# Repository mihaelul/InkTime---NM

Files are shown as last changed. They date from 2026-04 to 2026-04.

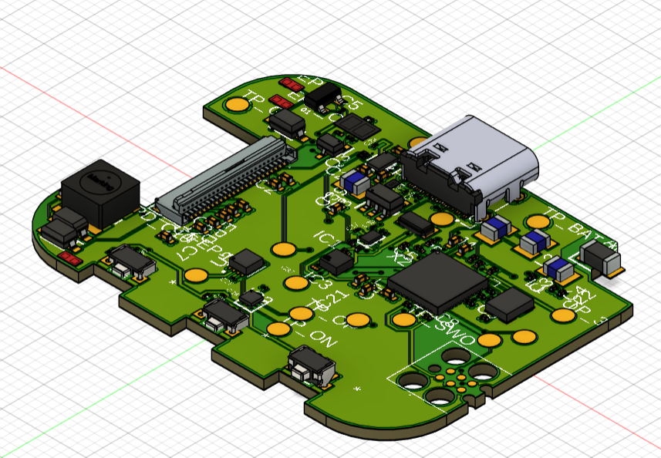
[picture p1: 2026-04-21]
Images/pcb3d-2.png

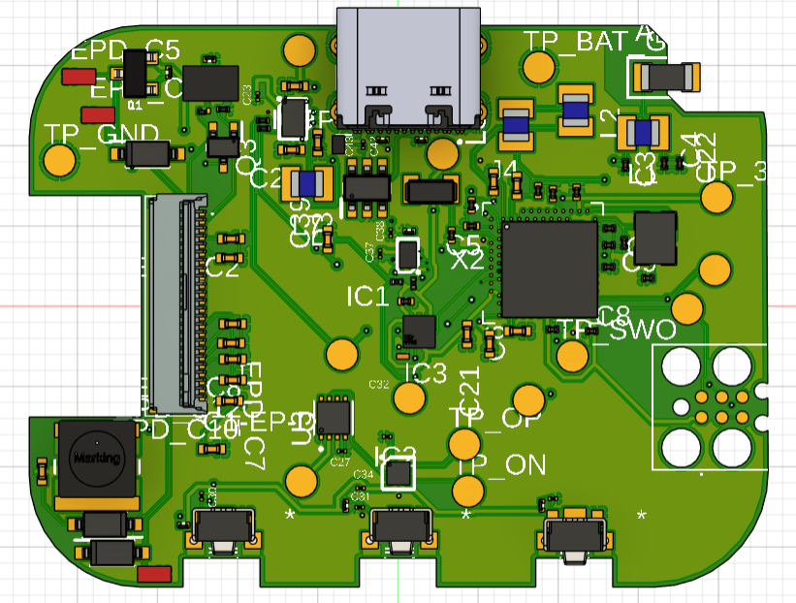
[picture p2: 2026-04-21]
Images/Front.png

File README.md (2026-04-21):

# InkTime - E-Paper Smartwatch Hardware Design

## 1. System Block Diagram
*This diagram illustrates the main hardware modules and their data/power connections to the central processing unit.*

```mermaid
graph TD

    ANTENNA[ANTENNA] ---|RF| SOC[nRF52840 <br> SoC]
    
    %% Peripherals and Interfaces
    SOC ---|I2C| IMU[IMU <br> SENSOR]
    SOC ---|SPI| EPD[E-PAPER <br> DISPLAY]
    SOC ---|PWM| SHAKER[SHAKER]
    SOC ---|GPIO| BTN[3X <br> BUTTON]
    SOC ---|SWD| DEBUG[DEBUG <br> SWD]

    USB[USB-C <br> CONNECTOR] ---|VUSB| CHARGER[CHARGER IC]
    CHARGER --- BATTERY[LI-PO BATTERY]
    CHARGER --- VREG[RT6160 <br> VOLTAGE <br> REGULATOR]
    BATTERY ---|VBAT| VREG

    %% 3V3 Power Rails
    VREG ---|3V3| IMU
    VREG ---|3V3| EPD
    VREG ---|3V3| SHAKER
```

## 1. Bill of Materials (BOM)

| Component | JLC Part # | Package | Description | Datasheet |
| :--- | :--- | :--- | :--- | :--- |
| **J1** | C122434 | SMD,P=0.5mm,Surface Mount，Right Angle | FFC & FPC Connectors 0.5mm FPC RA SMT Dual Contact 24Ckt | [datasheet](https://octopart.com/datasheet/tag-connect/TC2030-IDC) |
| **L1, L2, L3** | C12669 | 402 | Generic chip inductor | [datasheet](https://www.lcsc.com/datasheet/C12669.pdf) |
| **L5** | C1329646 | SMD,4.8x4.8mm | 1.6A 1.6A 4.7uH 41.4mΩ AEC-Q200 ±30% SMD,4.8x4.8mm Power Inductors ROHS | [datasheet](https://wmsc.lcsc.com/wmsc/upload/file/pdf/v2/lcsc/2304140030_BOURNS-SRR4828A-4R7Y_C1329646.pdf) |
| **IC3** | C189517 | LGA-12(2x2) | Accelerometers Triaxial low-g 12bit Acceleration Sensor | [datasheet](https://files.pine64.org/doc/datasheet/pinetime/BST-BMA421-FL000.pdf) |
| **Q1** | C2564 | TO-220AB | -55℃~+175℃ 1 P-Channel 180nC@10V 200W 20mΩ@10V 3.4nF 4V 55V 640pF 74A P-Channel TO-220AB MOSFETs ROHS | [datasheet](https://files.pine64.org/doc/datasheet/pinetime/BST-BMA421-FL000.pdf) |
| **U3** | C2682616 | DFN-8-EP(2x2) | -40℃~+85℃ 1 2.5V~4.5V 3uA I2C Lithium Battery DFN-8-EP(2x2) Battery Management ROHS | [datasheet](https://www.analog.com/en/products/max17048.html?ADICID=synd_ww_portfolio_pi_octopart_na_2024) |
| **ANT1** | C2917717 | 1206 | -45℃~+125℃ 0.5dBi 1.3mm 1.6mm 100MHz 2.45GHz 2W 3.2mm 50Ω Patch Antenna 1206 Antennas ROHS | [datasheet](https://www.alldatasheet.com/datasheet-pdf/pdf/348957/JOHANSON/2450AT18B100.html) |
| **D3** | C2969755 | SOT-23-6L | Low Cap. ESD Protection Auto SOT-23-6 STMicroelectronics USBLC6-2SC6Y, Dual Uni-Directional TVS Diode Array, 6-Pin SOT-23 | [datasheet](https://octopart.com/datasheet/stmicroelectronics/USBLC6-2SC6Y) |
| **X2** | C32346 | SMD3215-2P | -40℃~+85℃ 12.5pF 32.768kHz 70kΩ Crystal Oscillator ±20ppm SMD3215-2P Crystals ROHS | [datasheet](https://www.lcsc.com/datasheet/C32346.pdf) |
| **U1** | C3606653 | QFN-48(6x6) | nRF52840 | [datasheet](https://octopart.com/datasheet/nordic-semiconductor/NRF52840-QIAA-T) |
| **IC1** | C3682423 | DSBGA-8(1.1x1.6) | Charger IC Lithium Ion/Polymer, Lithium Iron Phosphate 8-DSBGA (1.6x1.1) | [datasheet](https://www.alldatasheet.com/datasheet-pdf/pdf/1359210/TI/BQ25180YBGR.html) |
| **R17-R18, R1_EP_DR, R1_USB, R2-R5, R7-R9, R_PWR_EPD, R_TYPE_SEL** | C3920633 | 0201 | 7.68k 0201 Thin Film Surface Mount Fixed Resistor +/-0.5% 870.031W CPF0201D7K68C1 |  |
| **Q3** | C469327 | SOT-323 | MOSFET N-Ch 30V 1.5A TrenchFET SC70 Vishay Si1308EDL-T1-GE3 N-channel MOSFET Transistor, 1.5 A, 30 V, 3-Pin SC-70 | [datasheet](https://4donline.ihs.com/images/VipMasterIC/IC/VISH/VISH-S-A0000692786/VISH-S-A0000692786-1.pdf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) |
| **SW_DN, SW_ENT, SW_UP** | C569760 | SMD,3.9x2.9mm | -40℃~+85℃ 1.6N 1.6mm 15V 2.9mm 20mA 3.9mm 500,000 Cycles IP67 J-Lead Rectangular Button SPST Surface Mount White With Bracket | [datasheet](https://wmsc.lcsc.com/wmsc/upload/file/pdf/v2/lcsc/2301111010_PANASONIC-EVPAKE31A_C569760.pdf) |
| **L7** | C5832368 | 1008 | 13mΩ 470nH 6.5A 7.5A ±20% 1008 Power Inductors ROHS | [datasheet](https://www.lcsc.com/datasheet/C5832368.pdf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) |
| **IC9** | C7065276 | WLCSP-15B(2.3x1.4) | Buck-Boost Regulator Positive Output Step-Up/Step-Down I2C DC-DC Controller IC 15-WL-CSP | [datasheet](https://www.alldatasheet.com/datasheet-pdf/pdf/1709403/RICHTEK/RT6160AWSC.html) |
| **J4** | C709357 | SMD | 16P Female Surface Mount, Right Angle Type-C SMD USB Connectors ROHS | [datasheet](https://www.lcsc.com/datasheet/C709357.pdf) |
| **IC2** | C81079 | DSBGA-9 | Haptic Driver for ERM/LRA with Built-In Library and Smart Loop Architecture | [datasheet](https://www.alldatasheet.com/datasheet-pdf/pdf/489356/TI/DRV2605.html) |
| **D2, D4, D5** | C82046 | SOD-123 | ON SEMICONDUCTOR - MBR0530 - DIODE, SCHOTTKY, 0.5A, 30V, SOD-123 | [datasheet](https://www.lcsc.com/datasheet/C82046.pdf) |
| **X1** | C9009 | SMD3225-4P | 32MHz Crystal Oscillator ±10ppm ±20ppm SMD3225-4P Crystals ROHS | [datasheet](https://www.lcsc.com/datasheet/C9009.pdf) |
| **J2** | C90533 | P=1mm | CABLE ADAPTER 6 POS | https://octopart.com/datasheet/tag-connect/TC2030-IDC |
| **C6, C14, C15, C20, C21, C24, C25, C33, C39** | C9900179830 | 0402 | Generic chip capacitor |  [datasheet](https://octopart.com/datasheet/kyocera-avx/0402YC104KAT2A) |
| **EPD_C1 - EPD_C12** | C9900179830 | 0402 | Generic chip capacitor | [datasheet](https://octopart.com/datasheet/kyocera-avx/0402YC104KAT2A) |
| **C1, C2, C3, C4, C5, C7, C8, C9, C10, C11, C12, C13, C16, C17, C18, C19** | C9900156064 | 0201 | Generic chip capacitor | [datasheet](https://www.we-online.com/components/products/datasheet/885012104003.pdf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) |

## 3. Hardware Functionality & Specifications

The InkTime hardware architecture is centered around a **30-day battery life** target, utilizing an ultra-low-power interrupt-driven design.

### 1. Core Processing & Connectivity
* **SoC:** **nRF52840** (ARM Cortex-M4F) handles BLE 5.0 connectivity and main system logic.
* **Clocking:** 32MHz crystal for high-speed operations and a 32.768kHz crystal for accurate RTC timekeeping during sleep.
* **Programming:** Integrated **SWD** interface accessible via a Tag-Connect TC2030 footprint.

### 2. Power Management System
* **Battery:** **250mAh LiPo** (AKYGA LP502030) providing the primary power source.
* **Charging:** **BQ25180** charger IC manages USB charging via I2C and signals MCU on power events.
* **Regulation:** **RT6160** Buck-Boost converter stabilizes the 3.3V system rail across the full battery voltage range.
* **Monitoring:** **MAX17048** Fuel Gauge tracks battery State of Charge (SoC) via I2C with precision.

### 3. Display & User Interface
* **Display:** **1.54" E-Paper** (200x200) connected via **SPI**.
* **Power Gating:** An **SI2301 P-FET** switch is used to completely cut power to the display circuit between refreshes to eliminate leakage.
* **Refresh Policy:** Partial refresh is triggered once per minute to minimize energy consumption.
* **Input:** Three side-mounted tactile buttons (Up, Down, Enter/Esc) configured with internal pull-ups and wake-on-low interrupts.

### 4. Sensors & Haptics (I2C Bus)
* **Motion Sensing:** **BMA421** Accelerometer provides step counting and gesture wake-up functionality.
* **Haptic Feedback:** **DRV2605L** driver controls an **ERM vibration motor** to provide tactile notifications.
* **Efficiency:** Both modules are strictly managed; the haptic driver is disabled via an Enable pin when not in use.

### 5. Energy Profile
* **Sleep Current:** System spends >95% of time in deep sleep with peripherals powered down.
* **Active Peaks:** Energy is primarily consumed during BLE transfers and 1-minute display updates (~8mAs per update).

## 4. Detailed Pinout & Design Justification (nRF52840)

The pin mapping for the nRF52840 was optimized for **Power Efficiency**, **Signal Integrity (RF)**, and **PCB Routing** (minimizing via count and crossing traces).

### Communication & Power Control
| Pin | Net Name | Component | Justification |
| :--- | :--- | :--- | :--- |
| **ANT** | RF_OUT | Ceramic Antenna | Dedicated RF output requiring a 50Ω matched trace to the antenna network. |
| **P0.06 / P0.07** | I2C_SDA / SCL | Shared I2C Bus | Shared bus for BMA421, MAX17048, DRV2605L, and BQ25180 to conserve pins and simplify routing. |
| **P0.02 / P0.03** | EPD_SCK / MOSI | E-Paper (SPI) | High-speed SPI clock and data for the display. |
| **P0.05** | EPD_CS | E-Paper (SPI) | Chip Select to keep the EPD controller inactive when the bus is shared. |
| **P0.15 / P0.16** | EPD_DC / RST | E-Paper Control | Dedicated pins for Data/Command toggling and hardware reset. |
| **P0.17** | EPD_BUSY | E-Paper Status | Monitors internal state, allowing the MCU to sleep during EPD refresh cycles. |
| **P1.01** | PWR_EPD | P-FET Gate (Q4) | **Critical:** High-side power gating to physically cut power to the EPD, eliminating standby leakage. |

### User Input & Interrupts
| Pin | Net Name | Component | Justification |
| :--- | :--- | :--- | :--- |
| **P0.13 / P0.14** | SW_UP / SW_DN | Nav Buttons | Configured with internal pull-ups. Supports "Wake-on-Low" to wake the SoC from deep sleep. |
| **P1.00** | SW_ENT | Enter Button | Placed on Port 1 to simplify physical trace routing to the right edge of the PCB. |
| **P0.08** | IMU_INT1 | BMA421 (INT) | Primary interrupt for step detection, waking the MCU only when necessary. |
| **P0.12** | HAPTIC_EN | DRV2605L | Completely disables the haptic driver IC when inactive to save microamps of quiescent current. |

### System Timing & Debug
| Pin | Net Name | Component | Justification |
| :--- | :--- | :--- | :--- |
| **XC1 / XC2** | 32M_XTAL | 32MHz Crystal | Essential for BLE radio operation and high-accuracy internal timing. |
| **XL1 / XL2** | 32K_XTAL | 32.768kHz Crystal | Low-power clock for the RTC, keeping time while the system is in deep sleep. |
| **SWDIO / CLK**| SWD_DATA / CLK | Tag-Connect J2 | Standard ARM programming interface, placed near the edge for easy access. |

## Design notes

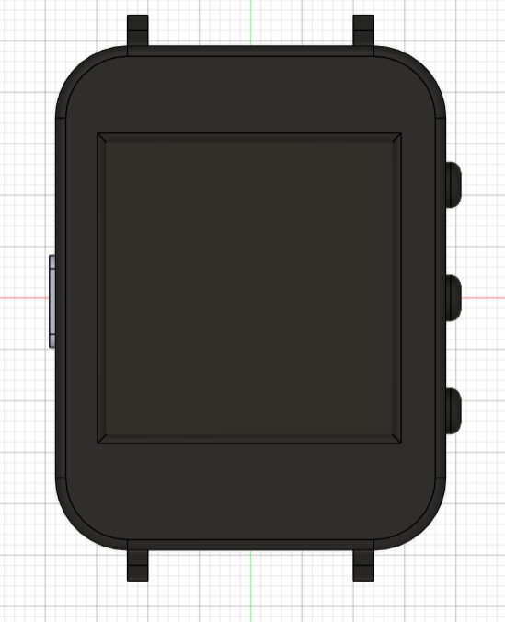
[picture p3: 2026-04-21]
Images/watch1.png

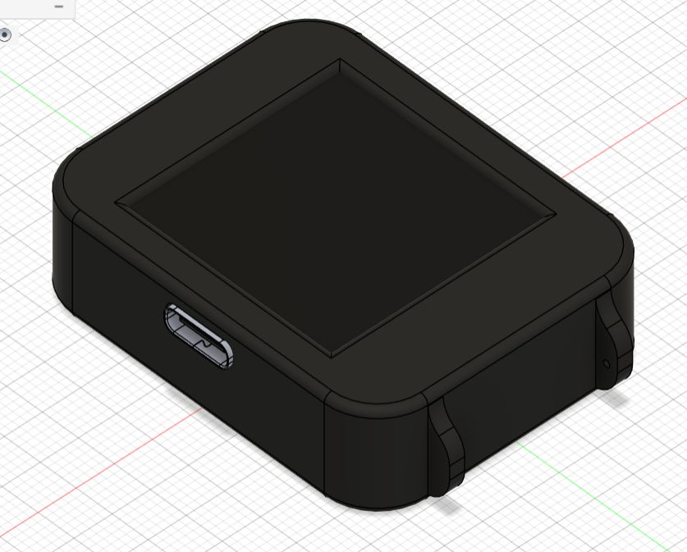
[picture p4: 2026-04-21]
Images/watch2.png

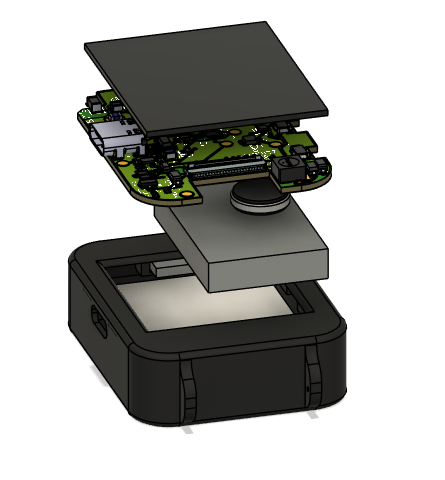
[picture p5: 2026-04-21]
Images/exploded.png

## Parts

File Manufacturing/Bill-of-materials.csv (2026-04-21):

Qty | Value | Device | Package | Parts | Description | ARROW_PART_NUMBER | ARROW_PRICE-STOCK | AVAILABILITY | CHECK_PRICES | COPYRIGHT | DESCRIPTION | DIGI-KEY_PART_NUMBER_1 | DIGI-KEY_PART_NUMBER_2 | DIGI-KEY_PART_NUMBER_3 | HEIGHT | JLCPCB | MANUFACTURER_NAME | MANUFACTURER_PART_NUMBER | MF | MFR_NAME | MOUSER_PART_NUMBER | MOUSER_PRICE-STOCK | MP | PACKAGE | POPULARITY | PRICE | PROD_ID | PURCHASE-URL | SNAPEDA_LINK | TP_SIGNAL_NAME | VALUE
1 |  | ESP32_C6_LIBRARY_7_JUMPER_SJ | ESP32_C6_LIBRARY_7_JUMPER_SJ | SJ1 | SMD solder JUMPER |  |  |  |  |  |  |  |  |  |  |  |  |  |  |  |  |  |  |  | 3
3 | 0 | CPF0201D7K68C1_CPF0201D7K68C1 | CPF0201D7K68C1_0201 | R2, R3, R4 | 7.68k 0201 Thin Film Surface Mount Fixed Resistor +/-0.5% 0.031W CPF0201D7K68C1
4 | 0.1uF | GRM011R60J152KE01L_2_GRM011R60J152KE01L | GRM011R60J152KE01L_2_CAPC0201X13N | C23, C27, C34, C42 | Check availability |  |  | In Stock | https://www.snapeda.com/parts/GRM011R60J152KE01L/Murata/view-part/?ref=eda |  | SMD Capacitor X5R(EIA) with Capacitance: 1500pF Tol. 10%. Rated Voltage: 6.3Vdc |  |  |  |  |  |  |  | Murata |  |  |  | GRM011R60J152KE01L | 0201 Murata |  | None |  |  | https://www.snapeda.com/parts/GRM011R60J152KE01L/Murata/view-part/?ref=snap
8 | 0.1uF/50V | NORDIC_NRF_3_CAPACITOR_0402_N | NORDIC_NRF_3_RESC0402_N | EPD_C5, EPD_C6, EPD_C7, EPD_C8, EPD_C9, EPD_C10, EPD_C11, EPD_C12 | Generic chip capacitor
1 | 0.47 | CPF0201D7K68C1_CPF0201D7K68C1 | CPF0201D7K68C1_0201 | R1_EP_DR | 7.68k 0201 Thin Film Surface Mount Fixed Resistor +/-0.5% 0.031W CPF0201D7K68C1
1 | 1.0µF | NORDIC_NRF_3_CAPACITOR_0402_N | NORDIC_NRF_3_RESC0402_N | C15 | Generic chip capacitor
2 | 100nF | NORDIC_NRF_3_CAPACITOR_0201_L | NORDIC_NRF_3_RESC0201_L | C7, C8 | Generic chip capacitor
3 | 100nF | NORDIC_NRF_3_CAPACITOR_0201_N | NORDIC_NRF_3_RESC0201_N | C5, C12, C19 | Generic chip capacitor
1 | 100pF | NORDIC_NRF_3_CAPACITOR_0201_L | NORDIC_NRF_3_RESC0201_L | C11 | Generic chip capacitor
2 | 10K | CPF0201D7K68C1_CPF0201D7K68C1 | CPF0201D7K68C1_0201 | R9, R_PWR_EPD | 7.68k 0201 Thin Film Surface Mount Fixed Resistor +/-0.5% 0.031W CPF0201D7K68C1
4 | 10k | CPF0201D7K68C1_CPF0201D7K68C1 | CPF0201D7K68C1_0201 | R2_EP_DR, R5, R7, R8 | 7.68k 0201 Thin Film Surface Mount Fixed Resistor +/-0.5% 0.031W CPF0201D7K68C1
3 | 10uF | NORDIC_NRF_3_CAPACITOR_0402_N | NORDIC_NRF_3_RESC0402_N | C1-EP-DR, C24, C39 | Generic chip capacitor
1 | 10µH | MLP2016SR47MT0S1_FTC252012SR47MBCA | MLP2016SR47MT0S1_INDC2016X100N | L2 | SMD / SMT Inductors (Coils), L=0.47?H, L x W x T : |  |  |  |  |  | SMD / SMT Inductors (Coils) | L=0.47?H | L x W x T : |  |  |  | 1mm | https://jlcpcb.com/partdetail/6763488-FTC252012SR47MBCA/C5832368 | TDK | FTC252012SR47MBCA
2 | 12pF | NORDIC_NRF_3_CAPACITOR_0201_L | NORDIC_NRF_3_RESC0201_L | C1, C2 | Generic chip capacitor
2 | 12pF | NORDIC_NRF_3_CAPACITOR_0201_N | NORDIC_NRF_3_RESC0201_N | C17, C18 | Generic chip capacitor
1 | 15nH | MLP2016SR47MT0S1_FTC252012SR47MBCA | MLP2016SR47MT0S1_INDC2016X100N | L3 | SMD / SMT Inductors (Coils), L=0.47?H, L x W x T : |  |  |  |  |  | SMD / SMT Inductors (Coils) | L=0.47?H | L x W x T : |  |  |  | 1mm | https://jlcpcb.com/partdetail/6763488-FTC252012SR47MBCA/C5832368 | TDK | FTC252012SR47MBCA
2 | 1pF | NORDIC_NRF_3_CAPACITOR_0201_L | NORDIC_NRF_3_RESC0201_L | C3, C4 | Generic chip capacitor
6 | 1uF | GRM011R60J152KE01L_2_GRM011R60J152KE01L | GRM011R60J152KE01L_2_CAPC0201X13N | C29, C30, C31, C32, C37, C38 | Check availability |  |  | In Stock | https://www.snapeda.com/parts/GRM011R60J152KE01L/Murata/view-part/?ref=eda |  | SMD Capacitor X5R(EIA) with Capacitance: 1500pF Tol. 10%. Rated Voltage: 6.3Vdc |  |  |  |  |  |  |  | Murata |  |  |  | GRM011R60J152KE01L | 0201 Murata |  | None |  |  | https://www.snapeda.com/parts/GRM011R60J152KE01L/Murata/view-part/?ref=snap
2 | 1uF/50V | NORDIC_NRF_3_CAPACITOR_0402_N | NORDIC_NRF_3_RESC0402_N | EPD_C1, EPD_C2 | Generic chip capacitor
1 | 2.2 | CPF0201D7K68C1_CPF0201D7K68C1 | CPF0201D7K68C1_0201 | R_TYPE_SEL | 7.68k 0201 Thin Film Surface Mount Fixed Resistor +/-0.5% 0.031W CPF0201D7K68C1
3 | 2025-10-22_07-23-44_LIBRARY_EVP-AKE31ASW_EVP-AKE31A_PAN | 2025-10-22_07-23-44_LIBRARY_EVP-AKE31ASW_EVP-AKE31A_PAN | 2025-10-22_07-23-44_LIBRARY_SW_EVP-AKE31A_PAN | SW_DN, SW_ENT, SW_UP |  |  |  |  |  | Copyright (C) 2025 Ultra Librarian. All rights reserved. |  | P123437TR-ND | P123437CT-ND | P123437DKR-ND |  |  | Panasonic | EVP-AKE31A
1 | 20V/4.2A/52mO/1.4W | ESP32_C6_LIBRARY_4_ESP32_WROVER_SPARKFUN-DISCRETESEMI_MOSFET_PCH-DMG2305UX-7 | ESP32_C6_LIBRARY_4_ESP32_C6_LIBRARY_4_ESP32_C6_LIBRARY_4_ESP32_C6_LIBRARY_4_ESP32_WROVER_SPARKFUN-DISCRETESEMI_SOT23-3 | Q1 | P-channel MOSFETs |  |  |  |  |  |  |  |  |  |  |  |  |  |  |  |  |  |  |  |  |  | TRAN-14388 |  |  |  | 20V/4.2A/52mO/1.4W
2 | 22uF | NORDIC_NRF_3_CAPACITOR_0402_N | NORDIC_NRF_3_RESC0402_N | C25, C33 | Generic chip capacitor
1 | 2450AT18B100E_2450AT18B100E | 2450AT18B100E_2450AT18B100E | 2450AT18B100E_ANTC3216X140N | ANT1 | Antennas 2.45GHz ANTENNA | 2450AT18B100E | https://www.arrow.com/en/products/2450at18b100e/johanson-dielectrics?utm_currency=USD&region=nac |  |  |  | Antennas 2.45GHz ANTENNA |  |  |  | 1.4mm |  | JOHANSON TECHNOLOGY | 2450AT18B100E |  |  | 609-2450AT18B100E | https://www.mouser.co.uk/ProductDetail/Johanson-Technology/2450AT18B100E?qs=yCnrNFeXz%252Bh5MFsFIXGZGA%3D%3D
1 | 3.9nH | MLP2016SR47MT0S1_FTC252012SR47MBCA | MLP2016SR47MT0S1_INDC2016X100N | L1 | SMD / SMT Inductors (Coils), L=0.47?H, L x W x T : |  |  |  |  |  | SMD / SMT Inductors (Coils) | L=0.47?H | L x W x T : |  |  |  | 1mm | https://jlcpcb.com/partdetail/6763488-FTC252012SR47MBCA/C5832368 | TDK | FTC252012SR47MBCA
1 | 32.768kHz | NORDIC_NRF_1_XTAL_32KHZ | NORDIC_NRF_1_XTAL_3215_N | X2
1 | 32MHz | NORDIC_NRF_XTAL_32MHZ | NORDIC_NRF_BT-XTAL_2016_N | X1
2 | 3K3 | CPF0201D7K68C1_CPF0201D7K68C1 | CPF0201D7K68C1_0201 | R17, R18 | 7.68k 0201 Thin Film Surface Mount Fixed Resistor +/-0.5% 0.031W CPF0201D7K68C1
1 | 4.7uF | GRM011R60J152KE01L_2_GRM011R60J152KE01L | GRM011R60J152KE01L_2_CAPC0201X13N | C43 | Check availability |  |  | In Stock | https://www.snapeda.com/parts/GRM011R60J152KE01L/Murata/view-part/?ref=eda |  | SMD Capacitor X5R(EIA) with Capacitance: 1500pF Tol. 10%. Rated Voltage: 6.3Vdc |  |  |  |  |  |  |  | Murata |  |  |  | GRM011R60J152KE01L | 0201 Murata |  | None |  |  | https://www.snapeda.com/parts/GRM011R60J152KE01L/Murata/view-part/?ref=snap
1 | 4.7uF/25V | NORDIC_NRF_3_CAPACITOR_0402_N | NORDIC_NRF_3_RESC0402_N | C2-EP-DR | Generic chip capacitor
4 | 4.7µF | NORDIC_NRF_3_CAPACITOR_0402_N | NORDIC_NRF_3_RESC0402_N | C6, C14, C20, C21 | Generic chip capacitor
1 | 47nF | NORDIC_NRF_3_CAPACITOR_0201_N | NORDIC_NRF_3_RESC0201_N | C16 | Generic chip capacitor
1 | 503480-2400_503480-2400 | 503480-2400_503480-2400 | 503480-2400_5034802400 | J3 | FFC & FPC Connectors 0.5mm FPC RA SMT Dual Contact 24Ckt |  |  |  |  |  | FFC & FPC Connectors 0.5mm FPC RA SMT Dual Contact 24Ckt |  |  |  | 1.87mm |  | Molex | 503480-2400 |  |  | 538-503480-2400 | https://www.mouser.co.uk/ProductDetail/Molex/503480-2400?qs=OAhjpuo3Vu7efIoxFh9AOw%3D%3D
2 | 5k1 | ERA-1AEB3401C_CPF0201D7K68C1 | ERA-1AEB3401C_0201 | R1_USB, R2_USB | 7.68k 0201 Thin Film Surface Mount Fixed Resistor +/-0.5% 0.031W CPF0201D7K68C1
1 | 68uH | ESP32_C6_LIBRARY_2_744043680IND_4828-WE-TPC_WRE | ESP32_C6_LIBRARY_2_IND_4828-WE-TPC_WRE | L5 |  |  |  |  |  | Copyright (C) 2024 Ultra Librarian. All rights reserved. |  |  |  |  |  |  |  | 744043680 |  | Wurth Electronics
1 | 820pF | NORDIC_NRF_3_CAPACITOR_0201_L | NORDIC_NRF_3_RESC0201_L | C9 | Generic chip capacitor
1 | BMA423_BMA423 | BMA423_BMA423 | BMA423_BMA423 | IC3 | Accelerometers Triaxial low-g 12bit Acceleration Sensor | BMA423 | https://www.arrow.com/en/products/bma423/bosch |  |  |  | Accelerometers Triaxial low-g 12bit Acceleration Sensor |  |  |  | 1mm |  | BOSCH | BMA423 |  |  | 262-BMA423 | https://www.mouser.co.uk/ProductDetail/Bosch-Sensortec/BMA423?qs=HXFqYaX1Q2xC%252BSgeGoX3mg%3D%3D
1 | BQ25180YBGR_BQ25180YBGR | BQ25180YBGR_BQ25180YBGR | BQ25180YBGR_BGA8C40P2X4_100X155X50 | IC1 | Charger IC Lithium Ion/Polymer, Lithium Iron Phosphate 8-DSBGA (1.6x1.1) | BQ25180YBGR | https://www.arrow.com/en/products/bq25180ybgr/texas-instruments?utm_currency=USD&region=nac |  |  |  | Charger IC Lithium Ion/Polymer | Lithium Iron Phosphate 8-DSBGA (1.6x1.1) |  |  |  | 0.5mm |  | Texas Instruments | BQ25180YBGR |  |  | 595-BQ25180YBGR | https://www.mouser.co.uk/ProductDetail/Texas-Instruments/BQ25180YBGR?qs=doiCPypUmgEWjAK%252BJAX6Tw%3D%3D
1 | DRV2605YZFR_DRV2605YZFR | DRV2605YZFR_DRV2605YZFR | DRV2605YZFR_BGA9C50P3X3_144X144X62 | IC2 | Haptic Driver for ERM/LRA with Built-In Library and Smart Loop Architecture | DRV2605YZFR | https://www.arrow.com/en/products/drv2605yzfr/texas-instruments?region=nac |  |  |  | Haptic Driver for ERM/LRA with Built-In Library and Smart Loop Architecture |  |  |  | 0.625mm |  | Texas Instruments | DRV2605YZFR
1 | ESP32_C6_LIBRARY_3_USBLC6-2SC6Y | ESP32_C6_LIBRARY_3_USBLC6-2SC6Y | ESP32_C6_LIBRARY_3_SOT95P280X145-6N | D3 | Low Cap. ESD Protection Auto SOT-23-6 STMicroelectronics USBLC6-2SC6Y, Dual Uni-Directional TVS Diode Array, 6-Pin SOT-23 |  |  | In Stock | https://www.snapeda.com/parts/USBLC6-2SC6Y/STMicroelectronics/view-part/?ref=eda |  | 17V Clamp 5A (8/20µs) Ipp Tvs Diode Surface Mount SOT-23-6 |  |  |  |  |  |  |  | STMicroelectronics |  |  |  | USBLC6-2SC6Y | SOT-23-6 STMicroelectronics |  | None |  |  | https://www.snapeda.com/parts/USBLC6-2SC6Y/STMicroelectronics/view-part/?ref=snap
1 | ESP32_C6_LIBRARY_MAX17048G+T10 | ESP32_C6_LIBRARY_MAX17048G+T10 | ESP32_C6_LIBRARY_SON50P200X200X80-9N | U3 | Check availability |  |  | In Stock | https://www.snapeda.com/parts/MAX17048G+T10/Analog+Devices/view-part/?ref=eda |  | 3µA 1-Cell/2-Cell Fuel Gauge with ModelGauge |  |  |  |  |  |  |  | Analog Devices |  |  |  | MAX17048G+T10 | TDFN-8 Maxim |  | None |  | https://www.snapeda.com/api/url_track_click_mouser/?unipart_id=329239&manufacturer=Analog Devices&part_name=MAX17048G+T10&search_term=None | https://www.snapeda.com/parts/MAX17048G+T10/Analog+Devices/view-part/?ref=snap
14 | HECTOR_WATCH_1_TPTP20R | HECTOR_WATCH_1_TPTP20R | HECTOR_WATCH_1_TP20R | TP_3.3V, TP_3V3, TP_BAT_GND, TP_GND, TP_ON, TP_OP, TP_RESET, TP_SCL, TP_SDA, TP_SWDCLK, TP_SWDIO, TP_SWO, TP_VBAT, TP_VREG | Test pad |  |  |  |  |  |  |  |  |  |  |  |  |  |  |  |  |  |  |  | 2
1 | KH-TYPE-C-16P_KH-TYPE-C-16P | KH-TYPE-C-16P_KH-TYPE-C-16P | KH-TYPE-C-16P_KINGHELM_KH-TYPE-C-16P | J4 | Check availability |  |  | Not in stock | https://www.snapeda.com/parts/KH-TYPE-C-16P/Kinghelm/view-part/?ref=eda |  |  |  |  |  |  |  |  |  | kinghelm |  |  |  | KH-TYPE-C-16P | None |  | None |  |  | https://www.snapeda.com/parts/KH-TYPE-C-16P/Kinghelm/view-part/?ref=snap
3 | MBR0530 | ESP32_C6_LIBRARY_5_MBR0530 | ESP32_C6_LIBRARY_5_SOD3716X135N | D2, D4, D5 | ON SEMICONDUCTOR - MBR0530 - DIODE, SCHOTTKY, 0.5A, 30V, SOD-123 |  |  | In Stock | https://www.snapeda.com/parts/MBR0530/Onsemi/view-part/?ref=eda |  | Diode Schottky 30 V 500mA Surface Mount SOD-123 |  |  |  |  |  |  |  | ON Semiconductor |  |  |  | MBR0530 | SOD-123-2 ON Semiconductor |  | None |  | https://www.snapeda.com/api/url_track_click_mouser/?unipart_id=179458&manufacturer=ON Semiconductor&part_name=MBR0530&search_term=None | https://www.snapeda.com/parts/MBR0530/Onsemi/view-part/?ref=snap
1 | MLP2016SR47MT0S1_FTC252012SR47MBCA | MLP2016SR47MT0S1_FTC252012SR47MBCA | MLP2016SR47MT0S1_INDC2016X100N | L7 | SMD / SMT Inductors (Coils), L=0.47?H, L x W x T : |  |  |  |  |  | SMD / SMT Inductors (Coils) | L=0.47?H | L x W x T : |  |  |  | 1mm | https://jlcpcb.com/partdetail/6763488-FTC252012SR47MBCA/C5832368 | TDK | FTC252012SR47MBCA
1 | N.C | NORDIC_NRF_3_CAPACITOR_0201_N | NORDIC_NRF_3_RESC0201_N | C13 | Generic chip capacitor
2 | N.C. | NORDIC_NRF_3_CAPACITOR_0201_L | NORDIC_NRF_3_RESC0201_L | C10, C22 | Generic chip capacitor
1 | NORDIC_NRF_4_NRF52840_QF | NORDIC_NRF_4_NRF52840_QF | NORDIC_NRF_4_AQFN50P700X700X85_HS-74N | U$1 | nRF52840
1 | RT6160AWSC_RT6160AWSC | RT6160AWSC_RT6160AWSC | RT6160AWSC_BGA15C40P3X5_140X230X60 | IC9 | Buck-Boost Regulator Positive Output Step-Up/Step-Down I2C DC-DC Controller IC 15-WL-CSP (BSC) (1.4x2.3) |  |  |  |  |  | Buck-Boost Regulator Positive Output Step-Up/Step-Down I2C DC-DC Controller IC 15-WL-CSP (BSC) (1.4x2.3) |  |  |  | 0.6mm |  | RICHTEK | RT6160AWSC |  |  | 835-RT6160AWSC | https://www.mouser.co.uk/ProductDetail/Richtek/RT6160AWSC?qs=amGC7iS6iy%2FLd9PSoixZXQ%3D%3D
1 | SI1308EDL-T1-GE3 | ESP32_C6_LIBRARY_6_SI1308EDL-T1-GE3 | ESP32_C6_LIBRARY_6_SOT65P210X110-3N | Q3 | MOSFET N-Ch 30V 1.5A TrenchFET SC70 Vishay Si1308EDL-T1-GE3 N-channel MOSFET Transistor, 1.5 A, 30 V, 3-Pin SC-70 |  |  | In Stock | https://www.snapeda.com/parts/SI1308EDL-T1-GE3/Vishay+Siliconix/view-part/?ref=eda |  | Si1308EDL-T1-GE3 N-channel MOSFET Transistor | 1.5 A | 30 V | 3-Pin SC-70 | Siliconix / Vishay SI1308EDL-T1-GE3 |  |  |  |  |  |  |  | Vishay Siliconix |  |  |  | SI1308EDL-T1-GE3 | SOT-323 Vishay Semiconductor |  | None |  | https://www.snapeda.com/api/url_track_click_mouser/?unipart_id=274603&manufacturer=Vishay Siliconix&part_name=SI1308EDL-T1-GE3&search_term=None
1 | TC2030-IDC_TC2030-IDC | TC2030-IDC_TC2030-IDC | TC2030-IDC_TC2030IDC | J2 | CABLE ADAPTER 6 POS |  |  |  |  |  | CABLE ADAPTER 6 POS |  |  |  | 19mm |  | Tag Connect | TC2030-IDC

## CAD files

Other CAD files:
Mechanical/3dpcb.f3z

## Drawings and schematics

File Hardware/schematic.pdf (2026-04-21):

# E-Paper Drive Circuit Haptic Driver

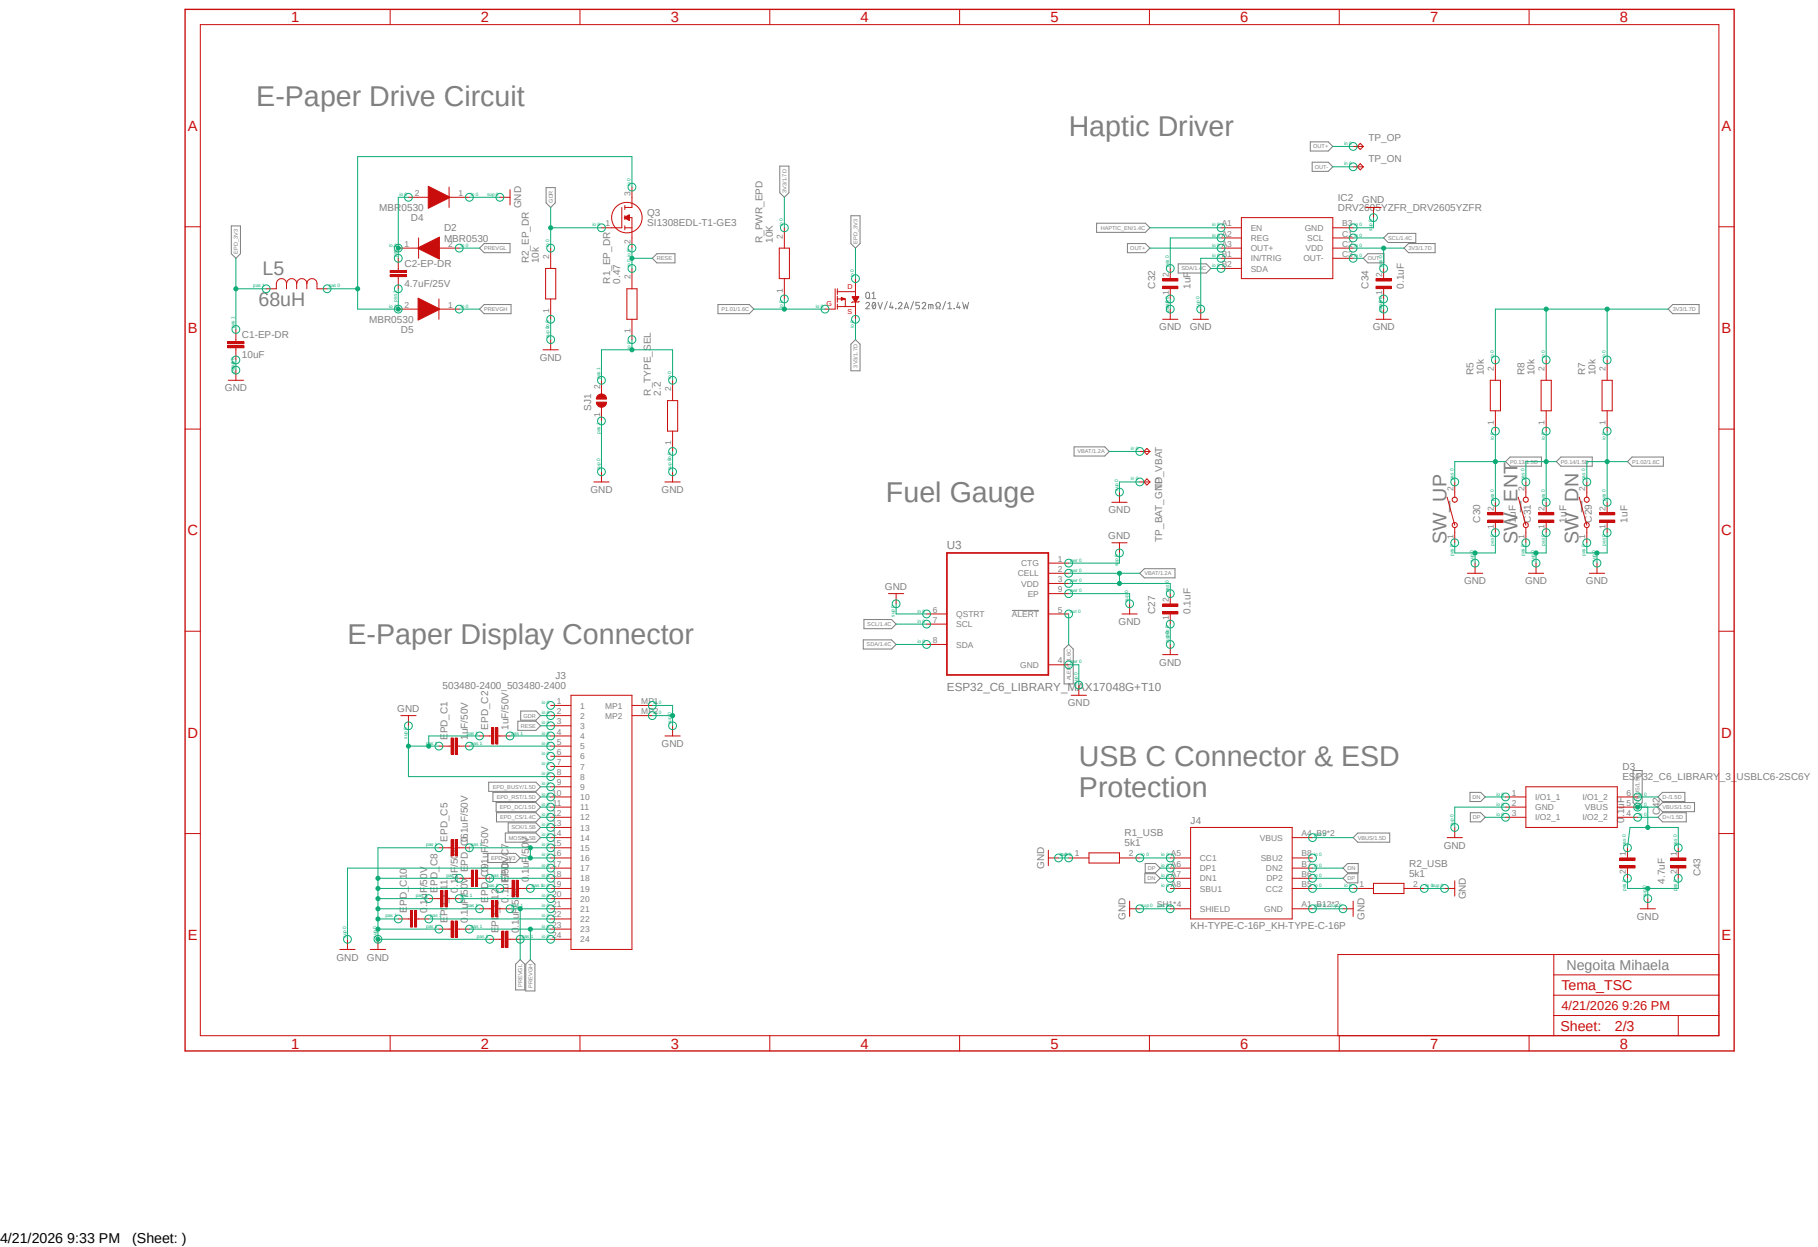
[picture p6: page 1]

pas 1 | pas 1 io 0 | 18 18

pas 1 | pas 1 | io 0 | 20 20

pas 1 | pas 1 io 0 | 19 19

pas 1 | pas 1 io 0 | 21 21

pas 1 | pas 1 | | io 0 | 22 22

pas 1 | pas 1 | io 0 | 23 23

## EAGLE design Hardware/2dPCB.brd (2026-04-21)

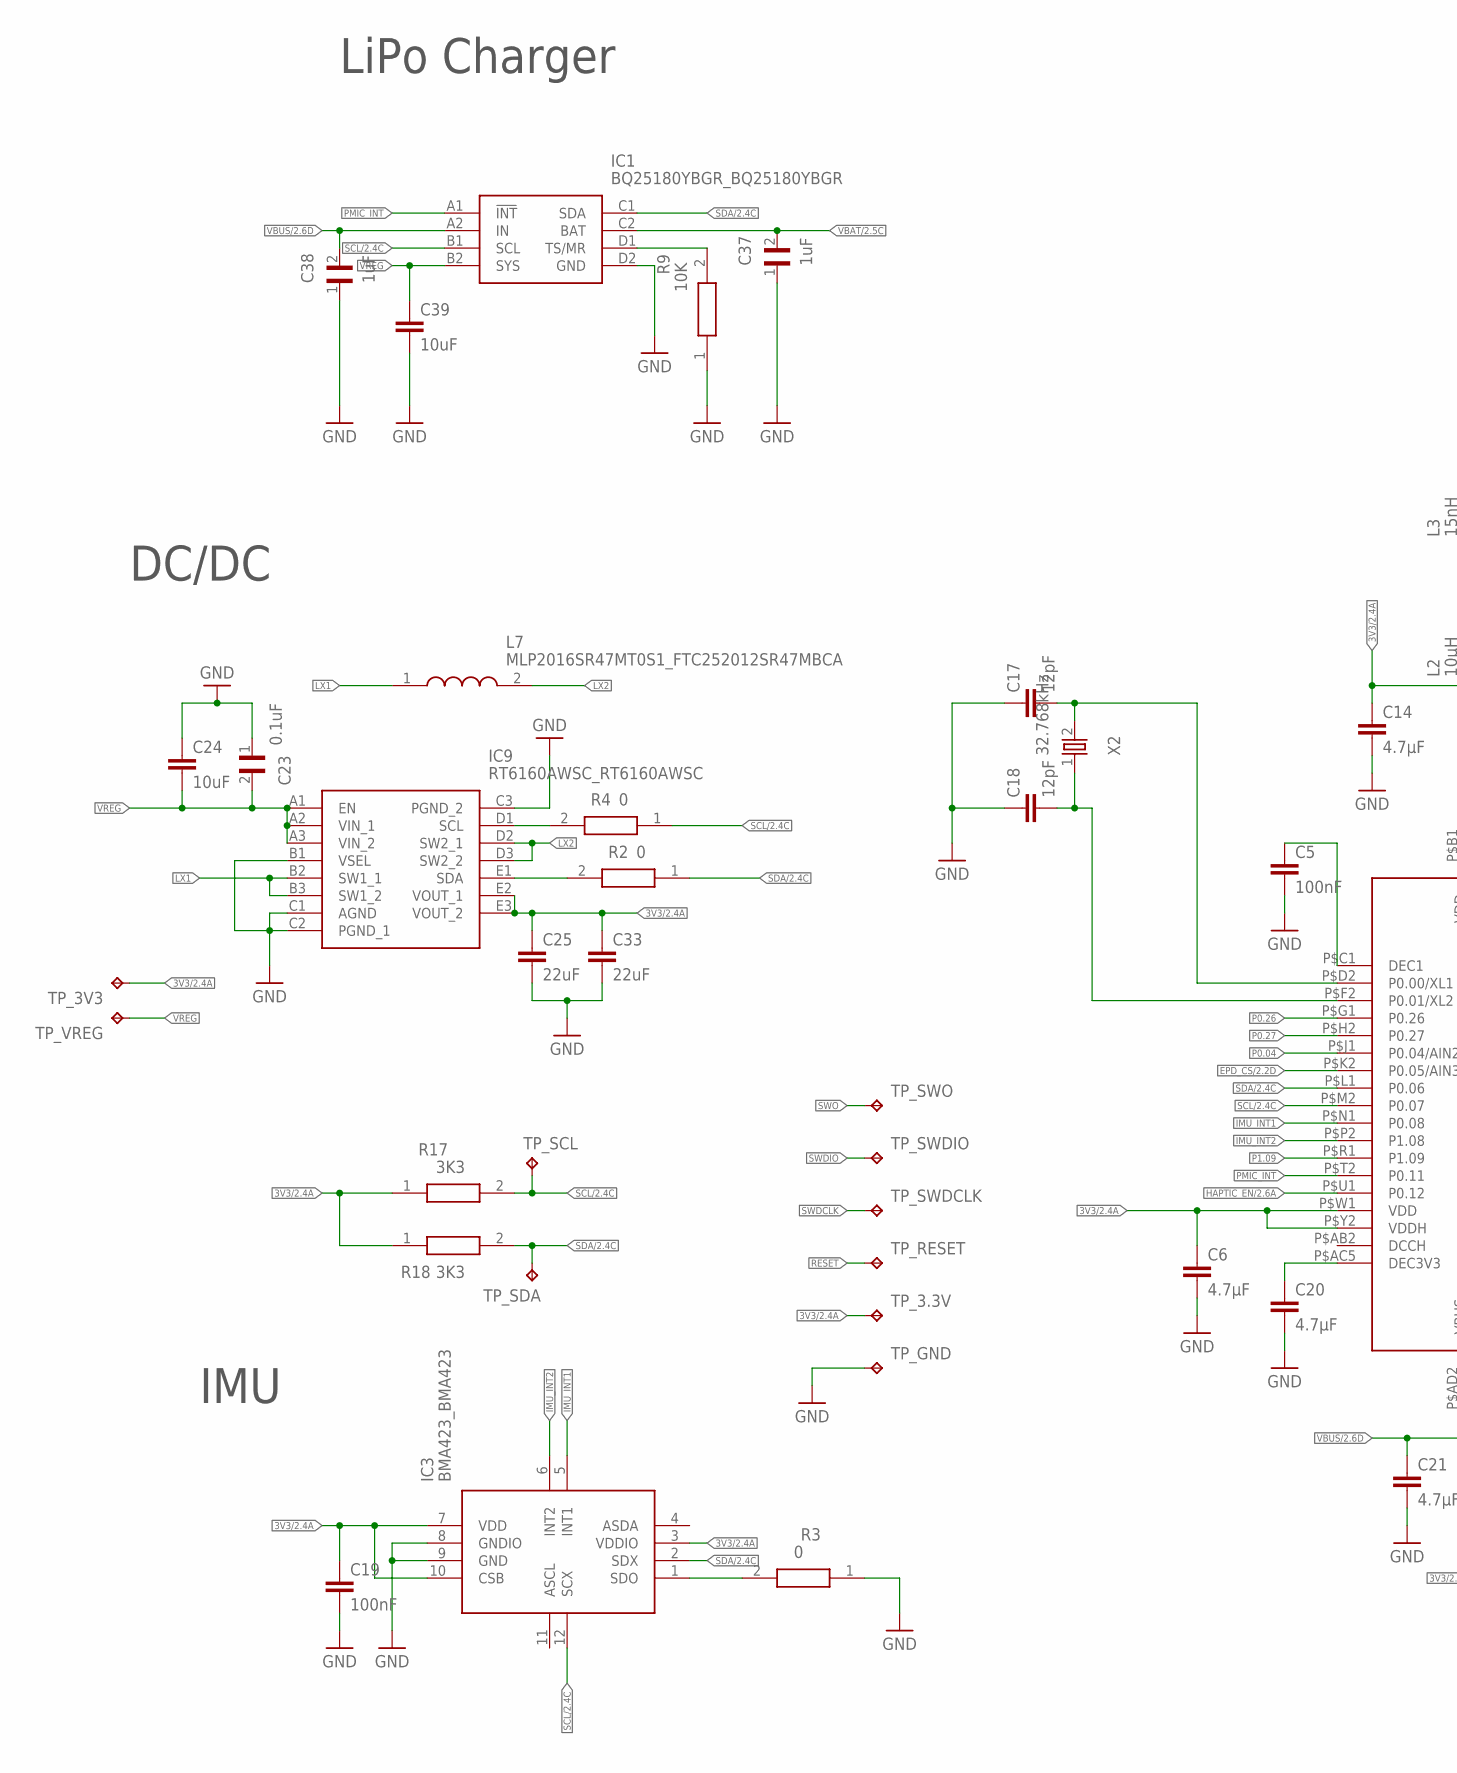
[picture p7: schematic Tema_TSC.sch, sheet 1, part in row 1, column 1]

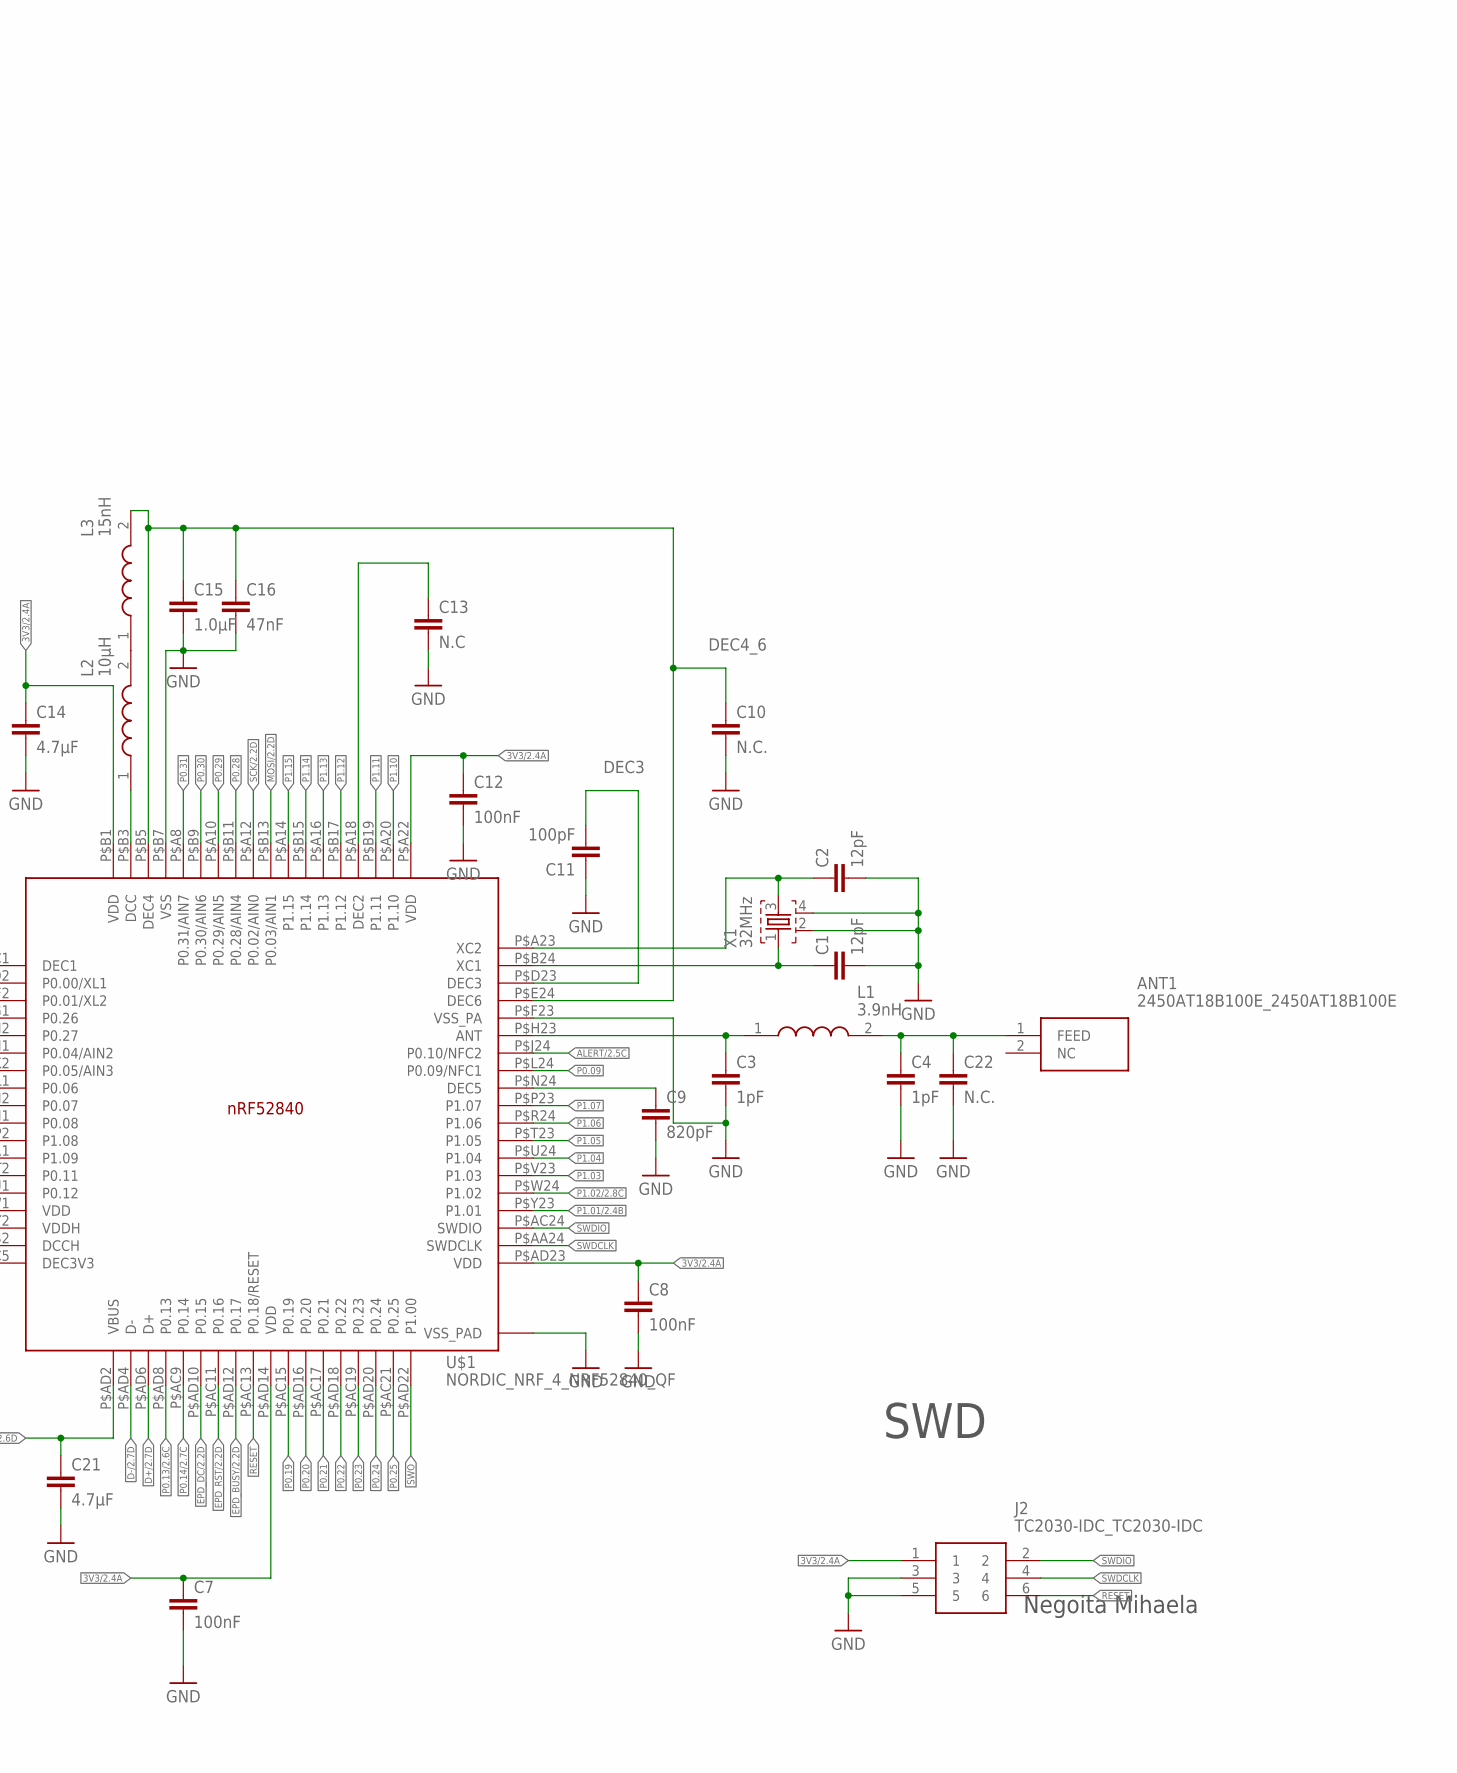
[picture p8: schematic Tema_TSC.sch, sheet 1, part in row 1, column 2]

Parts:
ANT1: 2450AT18B100E_2450AT18B100E; 2450AT18B100E_ANTC3216X140N
C1, C2: 12pF; NORDIC_NRF_3_RESC0201_L
C3, C4: 1pF; NORDIC_NRF_3_RESC0201_L
C5, C12, C19: 100nF; NORDIC_NRF_3_RESC0201_N
C6, C14, C20, C21: 4.7µF; NORDIC_NRF_3_RESC0402_N
C7, C8: 100nF; NORDIC_NRF_3_RESC0201_L
C9: 820pF; NORDIC_NRF_3_RESC0201_L
C10, C22: N.C.; NORDIC_NRF_3_RESC0201_L
C11: 100pF; NORDIC_NRF_3_RESC0201_L
C13: N.C; NORDIC_NRF_3_RESC0201_N
C15: 1.0µF; NORDIC_NRF_3_RESC0402_N
C16: 47nF; NORDIC_NRF_3_RESC0201_N
C17, C18: 12pF; NORDIC_NRF_3_RESC0201_N
C23: 0.1uF; GRM011R60J152KE01L_2_CAPC0201X13N
C24, C39: 10uF; NORDIC_NRF_3_RESC0402_N
C25, C33: 22uF; NORDIC_NRF_3_RESC0402_N
C37, C38: 1uF; GRM011R60J152KE01L_2_CAPC0201X13N
IC1: BQ25180YBGR_BQ25180YBGR; BQ25180YBGR_BGA8C40P2X4_100X155X50
IC3: BMA423_BMA423
IC9: RT6160AWSC_RT6160AWSC; RT6160AWSC_BGA15C40P3X5_140X230X60
J2: TC2030-IDC_TC2030-IDC; TC2030-IDC_TC2030IDC
L1: 3.9nH; MLP2016SR47MT0S1_INDC2016X100N
L2: 10µH; MLP2016SR47MT0S1_INDC2016X100N
L3: 15nH; MLP2016SR47MT0S1_INDC2016X100N
L7: MLP2016SR47MT0S1_FTC252012SR47MBCA; MLP2016SR47MT0S1_INDC2016X100N
R2, R3, R4: 0; CPF0201D7K68C1_0201
R9: 10K; CPF0201D7K68C1_0201
R17, R18: 3K3; CPF0201D7K68C1_0201
TP_3.3V, TP_3V3: HECTOR_WATCH_1_TPTP20R; HECTOR_WATCH_1_TP20R
TP_GND: HECTOR_WATCH_1_TPTP20R; HECTOR_WATCH_1_TP20R
TP_RESET: HECTOR_WATCH_1_TPTP20R; HECTOR_WATCH_1_TP20R
TP_SCL: HECTOR_WATCH_1_TPTP20R; HECTOR_WATCH_1_TP20R
TP_SDA: HECTOR_WATCH_1_TPTP20R; HECTOR_WATCH_1_TP20R
TP_SWDCLK: HECTOR_WATCH_1_TPTP20R; HECTOR_WATCH_1_TP20R
TP_SWDIO: HECTOR_WATCH_1_TPTP20R; HECTOR_WATCH_1_TP20R
TP_SWO: HECTOR_WATCH_1_TPTP20R; HECTOR_WATCH_1_TP20R
TP_VREG: HECTOR_WATCH_1_TPTP20R; HECTOR_WATCH_1_TP20R
U$1: NORDIC_NRF_4_NRF52840_QF; NORDIC_NRF_4_AQFN50P700X700X85_HS-74N
X1: 32MHz; NORDIC_NRF_BT-XTAL_2016_N
X2: 32.768kHz; NORDIC_NRF_1_XTAL_3215_N

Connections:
3V3/2.4A: C6.1, C7.1, C8.1, C12.1, C14.1, C19.1, C25.1, C33.1, IC3.3 (VDDIO), IC3.7 (VDD), IC3.10 (CSB), IC9.E2 (VOUT_1), IC9.E3 (VOUT_2), J2.1, R17.1, R18.1, TP_3.3V.TP, TP_3V3.TP, U$1.P$A22 (VDD), U$1.P$AD14 (VDD), U$1.P$AD23 (VDD), U$1.P$B1 (VDD), U$1.P$W1 (VDD), U$1.P$Y2 (VDDH)
ALERT/2.5C: U$1.P$J24 (P0.10/NFC2)
D+/2.7D: U$1.P$AD6 (D+)
D-/2.7D: U$1.P$AD4 (D-)
DEC3: C11.2, U$1.P$D23 (DEC3)
DEC4_6: C10.1, C15.1, C16.1, L3.2, U$1.P$B5 (DEC4), U$1.P$E24 (DEC6)
EPD_BUSY/2.2D: U$1.P$AD12 (P0.17)
EPD_CS/2.2D: U$1.P$K2 (P0.05/AIN3)
EPD_DC/2.2D: U$1.P$AD10 (P0.15)
EPD_RST/2.2D: U$1.P$AC11 (P0.16)
GND: C1.2, C2.2, C3.2, C4.2, C5.2, C6.2, C7.2, C8.2, C9.2, C10.2, C11.1, C12.2, C13.2, C14.2, C15.2, C16.2, C17.1, C18.1, C19.2, C20.2, C21.2, C22.2, C23.1, C24.1, C25.2, C33.2, C37.1, C38.1, C39.2, IC1.D2 (GND), IC3.8 (GNDIO), IC3.9 (GND), IC9.B1 (VSEL), IC9.C1 (AGND), IC9.C2 (PGND_1), IC9.C3 (PGND_2), J2.3, J2.5, R3.1, R9.1, TP_GND.TP, U$1.P$74 (VSS_PAD), U$1.P$75 (VSS_PAD), U$1.P$76 (VSS_PAD), U$1.P$77 (VSS_PAD), U$1.P$78 (VSS_PAD), U$1.P$79 (VSS_PAD), U$1.P$80 (VSS_PAD), U$1.P$81 (VSS_PAD), U$1.P$82 (VSS_PAD), U$1.P$83 (VSS_PAD), U$1.P$84 (VSS_PAD), U$1.P$85 (VSS_PAD), U$1.P$86 (VSS_PAD), U$1.P$87 (VSS_PAD), U$1.P$88 (VSS_PAD), U$1.P$89 (VSS_PAD), U$1.P$90 (VSS_PAD), U$1.P$B7 (VSS), U$1.P$F23 (VSS_PA), X1.2, X1.4; also elsewhere on the board
HAPTIC_EN/2.6A: U$1.P$U1 (P0.12)
IMU_INT1: IC3.5 (INT1), U$1.P$N1 (P0.08)
IMU_INT2: IC3.6 (INT2), U$1.P$P2 (P1.08)
LX1: IC9.B2 (SW1_1), IC9.B3 (SW1_2), L7.1
LX2: IC9.D2 (SW2_1), IC9.D3 (SW2_2), L7.2
MOSI/2.2D: U$1.P$B13 (P0.03/AIN1)
unnamed: C2.1, U$1.P$A23 (XC2), X1.3
unnamed: C1.1, U$1.P$B24 (XC1), X1.1
unnamed: C3.1, L1.1, U$1.P$H23 (ANT)
unnamed: L2.1, U$1.P$B3 (DCC)
unnamed: L2.2, L3.1
unnamed: ANT1.1 (FEED), C4.1, C22.1, L1.2
unnamed: C20.1, U$1.P$AC5 (DEC3V3)
unnamed: C5.1, U$1.P$C1 (DEC1)
unnamed: C17.2, U$1.P$D2 (P0.00/XL1), X2.2
unnamed: C18.2, U$1.P$F2 (P0.01/XL2), X2.1
unnamed: C13.1, U$1.P$A18 (DEC2)
unnamed: IC9.D1 (SCL), R4.2
unnamed: IC9.E1 (SDA), R2.2
unnamed: IC1.D1 (TS/MR), R9.2
unnamed: IC3.1 (SDO), R3.2
unnamed: C9.1, U$1.P$N24 (DEC5)
P0.04: U$1.P$J1 (P0.04/AIN2)
P0.09: U$1.P$L24 (P0.09/NFC1)
P0.13/2.6C: U$1.P$AD8 (P0.13)
P0.14/2.7C: U$1.P$AC9 (P0.14)
P0.19: U$1.P$AC15 (P0.19)
P0.20: U$1.P$AD16 (P0.20)
P0.21: U$1.P$AC17 (P0.21)
P0.22: U$1.P$AD18 (P0.22)
P0.23: U$1.P$AC19 (P0.23)
P0.24: U$1.P$AD20 (P0.24)
P0.25: U$1.P$AC21 (P0.25)
P0.26: U$1.P$G1 (P0.26)
P0.27: U$1.P$H2 (P0.27)
P0.28: U$1.P$B11 (P0.28/AIN4)
P0.29: U$1.P$A10 (P0.29/AIN5)
P0.30: U$1.P$B9 (P0.30/AIN6)
P0.31: U$1.P$A8 (P0.31/AIN7)
P1.01/2.4B: U$1.P$Y23 (P1.01)
P1.02/2.8C: U$1.P$W24 (P1.02)
P1.03: U$1.P$V23 (P1.03)
P1.04: U$1.P$U24 (P1.04)
P1.05: U$1.P$T23 (P1.05)
P1.06: U$1.P$R24 (P1.06)
P1.07: U$1.P$P23 (P1.07)
P1.09: U$1.P$R1 (P1.09)
P1.10: U$1.P$A20 (P1.10)
P1.11: U$1.P$B19 (P1.11)
P1.12: U$1.P$B17 (P1.12)
P1.13: U$1.P$A16 (P1.13)
P1.14: U$1.P$B15 (P1.14)
P1.15: U$1.P$A14 (P1.15)
PMIC_INT: IC1.A1 (!INT), U$1.P$T2 (P0.11)
RESET: J2.6, TP_RESET.TP, U$1.P$AC13 (P0.18/RESET)
SCK/2.2D: U$1.P$A12 (P0.02/AIN0)
SCL/2.4C: IC1.B1 (SCL), IC3.12 (SCX), R4.1, R17.2, TP_SCL.TP, U$1.P$M2 (P0.07)
SDA/2.4C: IC1.C1 (SDA), IC3.2 (SDX), R2.1, R18.2, TP_SDA.TP, U$1.P$L1 (P0.06)
SWDCLK: J2.4, TP_SWDCLK.TP, U$1.P$AA24 (SWDCLK)
SWDIO: J2.2, TP_SWDIO.TP, U$1.P$AC24 (SWDIO)
SWO: TP_SWO.TP, U$1.P$AD22 (P1.00)
VBAT/2.5C: C37.2, IC1.C2 (BAT)
VBUS/2.6D: C21.1, C38.2, IC1.A2 (IN), U$1.P$AD2 (VBUS)
VREG: C23.2, C24.2, C39.1, IC1.B2 (SYS), IC9.A1 (EN), IC9.A2 (VIN_1), IC9.A3 (VIN_2), TP_VREG.TP

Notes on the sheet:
LiPo Charger
DC/DC
IMU
SWD
Negoita Mihaela

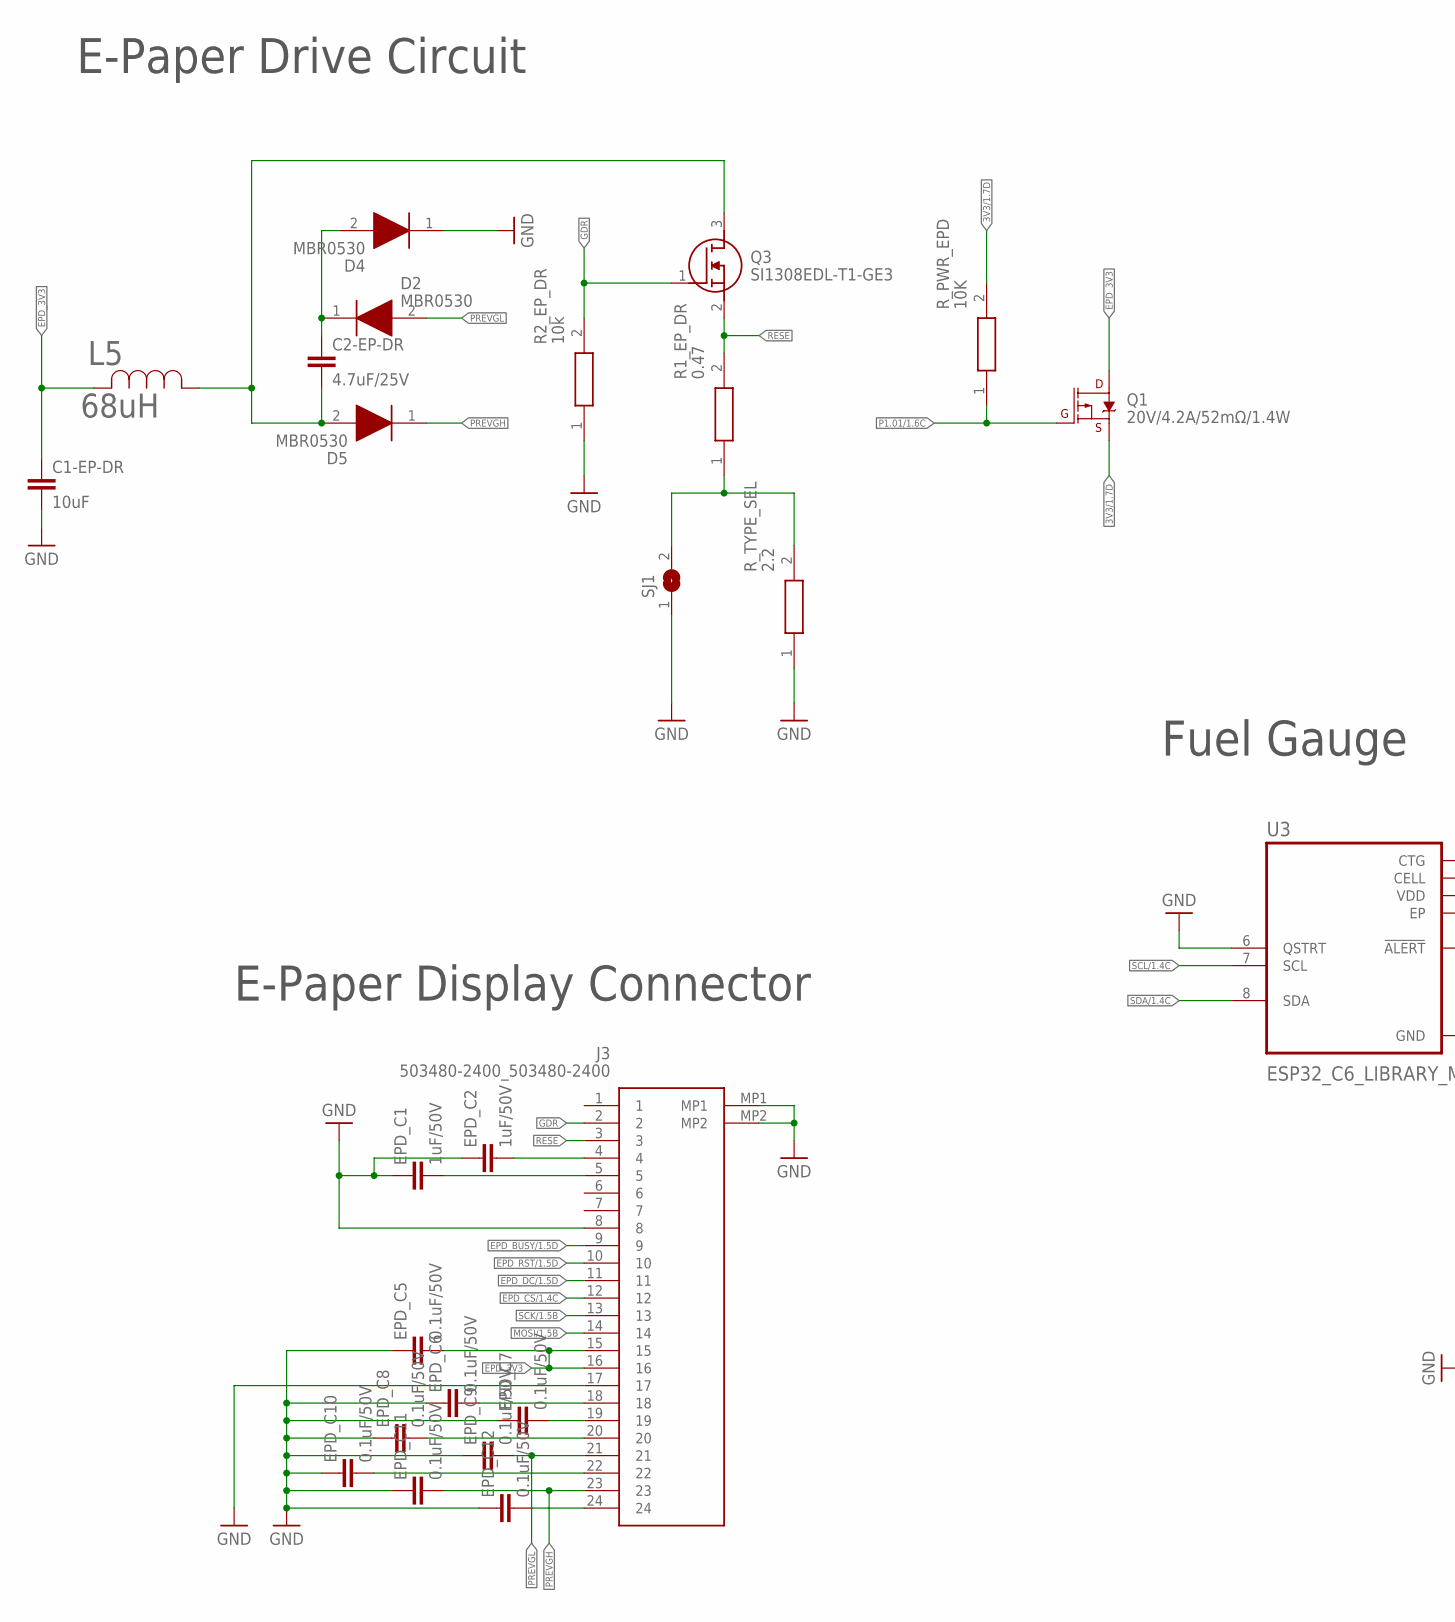
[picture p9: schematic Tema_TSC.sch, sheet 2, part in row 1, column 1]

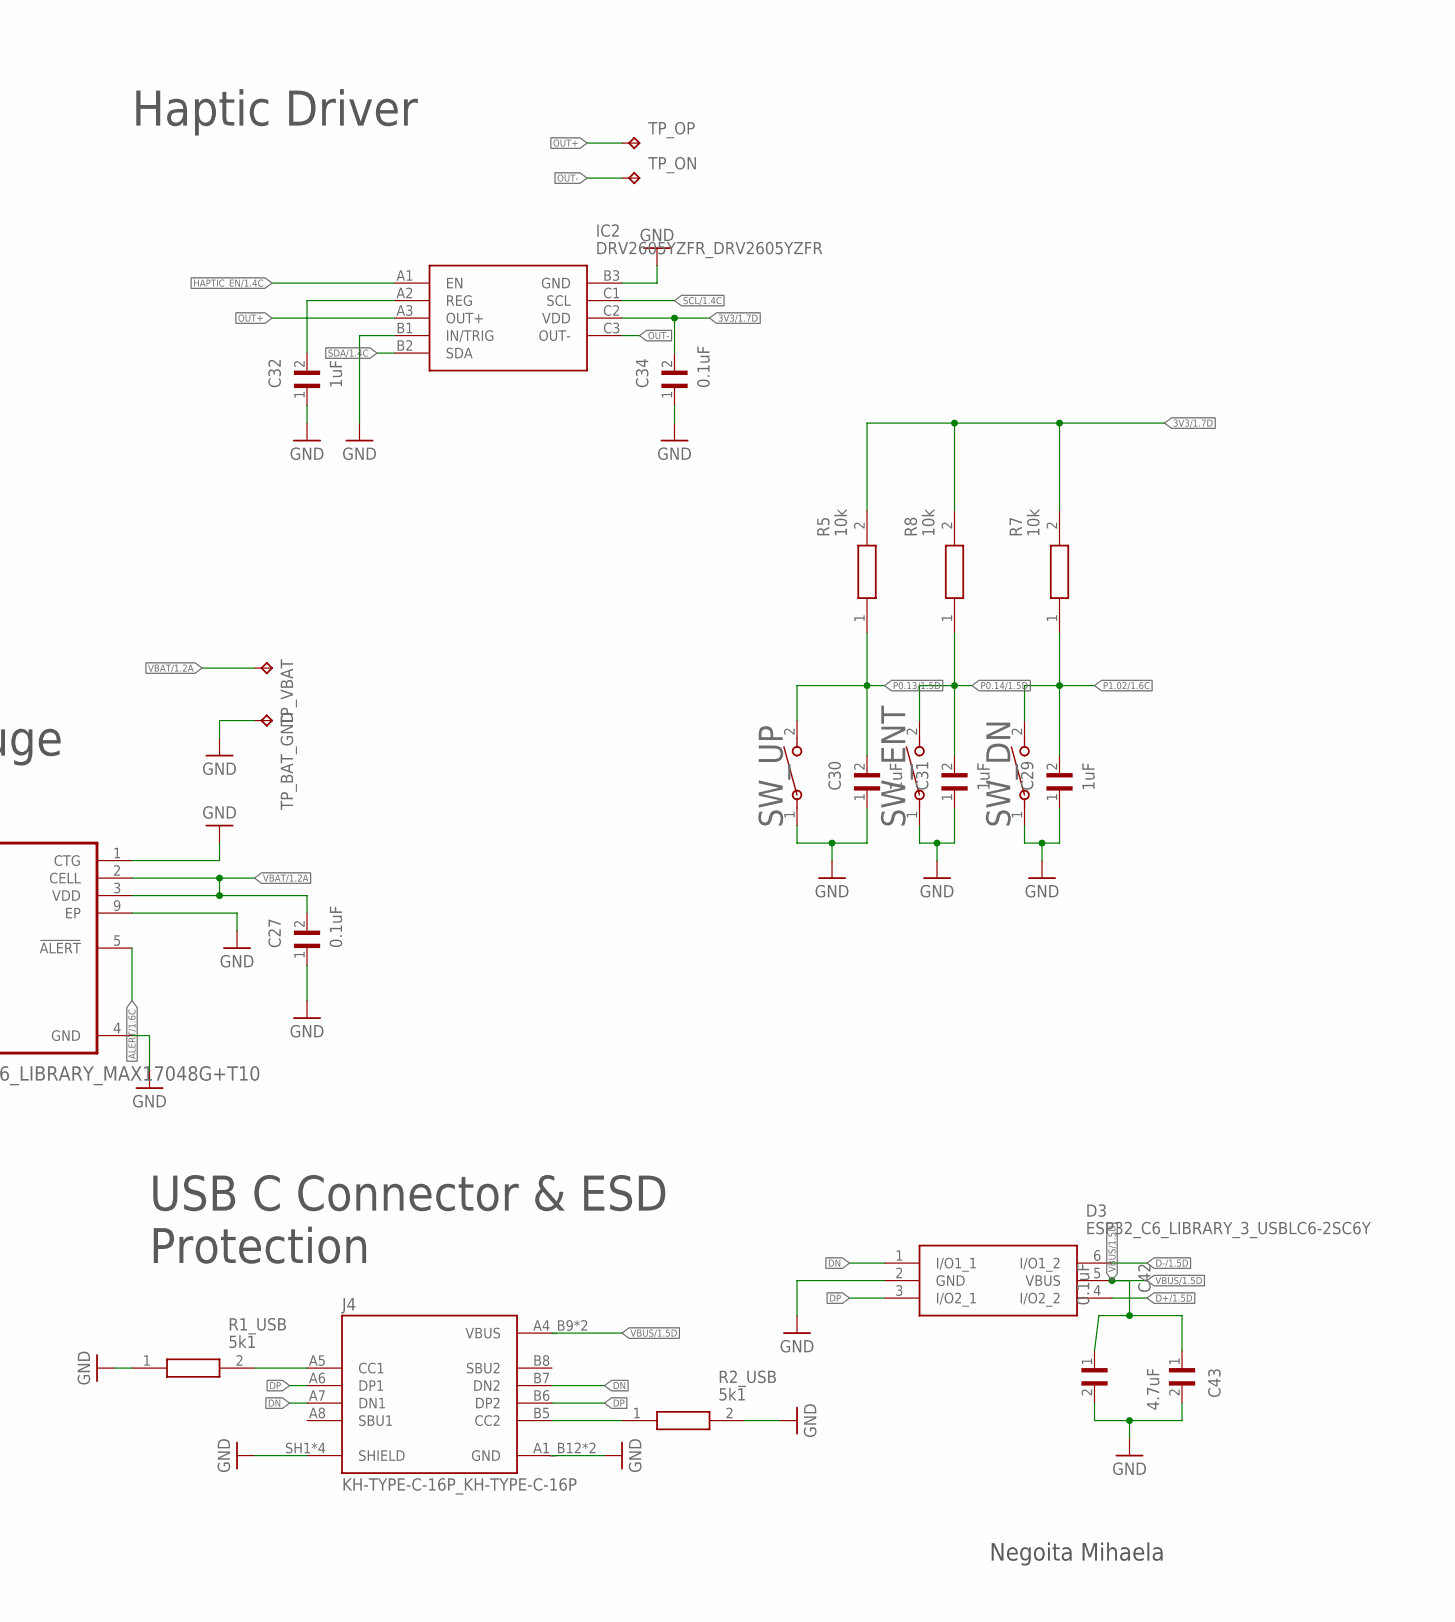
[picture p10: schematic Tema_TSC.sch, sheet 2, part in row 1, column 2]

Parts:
C1-EP-DR: 10uF; NORDIC_NRF_3_RESC0402_N
C2-EP-DR: 4.7uF/25V; NORDIC_NRF_3_RESC0402_N
C27, C34, C42: 0.1uF; GRM011R60J152KE01L_2_CAPC0201X13N
C29, C30, C31, C32: 1uF; GRM011R60J152KE01L_2_CAPC0201X13N
C43: 4.7uF; GRM011R60J152KE01L_2_CAPC0201X13N
D2, D4, D5: MBR0530; ESP32_C6_LIBRARY_5_SOD3716X135N
D3: ESP32_C6_LIBRARY_3_USBLC6-2SC6Y; ESP32_C6_LIBRARY_3_SOT95P280X145-6N
EPD_C1, EPD_C2: 1uF/50V; NORDIC_NRF_3_RESC0402_N
EPD_C5, EPD_C6, EPD_C7, EPD_C8, EPD_C9, EPD_C10, EPD_C11, EPD_C12: 0.1uF/50V; NORDIC_NRF_3_RESC0402_N
IC2: DRV2605YZFR_DRV2605YZFR; DRV2605YZFR_BGA9C50P3X3_144X144X62
J3: 503480-2400_503480-2400; 503480-2400_5034802400
J4: KH-TYPE-C-16P_KH-TYPE-C-16P; KH-TYPE-C-16P_KINGHELM_KH-TYPE-C-16P
L5: 68uH; ESP32_C6_LIBRARY_2_IND_4828-WE-TPC_WRE
Q1: 20V/4.2A/52mΩ/1.4W; ESP32_C6_LIBRARY_4_ESP32_C6_LIBRARY_4_ESP32_C6_LIBRARY_4_ES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
Q3: SI1308EDL-T1-GE3; ESP32_C6_LIBRARY_6_SOT65P210X110-3N
R1_EP_DR: 0.47; CPF0201D7K68C1_0201
R1_USB, R2_USB: 5k1; ERA-1AEB3401C_0201
R2_EP_DR, R5, R7, R8: 10k; CPF0201D7K68C1_0201
R_PWR_EPD: 10K; CPF0201D7K68C1_0201
R_TYPE_SEL: 2.2; CPF0201D7K68C1_0201
SJ1: ESP32_C6_LIBRARY_7_JUMPER_SJ
SW_DN: 2025-10-22_07-23-44_LIBRARY_EVP-AKE31ASW_EVP-AKE3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; 2025-10-22_07-23-44_LIBRARY_SW_EVP-AKE31A_PAN
SW_ENT: 2025-10-22_07-23-44_LIBRARY_EVP-AKE31ASW_EVP-AKE3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; 2025-10-22_07-23-44_LIBRARY_SW_EVP-AKE31A_PAN
SW_UP: 2025-10-22_07-23-44_LIBRARY_EVP-AKE31ASW_EVP-AKE3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; 2025-10-22_07-23-44_LIBRARY_SW_EVP-AKE31A_PAN
TP_BAT_GND: HECTOR_WATCH_1_TPTP20R; HECTOR_WATCH_1_TP20R
TP_ON: HECTOR_WATCH_1_TPTP20R; HECTOR_WATCH_1_TP20R
TP_OP: HECTOR_WATCH_1_TPTP20R; HECTOR_WATCH_1_TP20R
TP_VBAT: HECTOR_WATCH_1_TPTP20R; HECTOR_WATCH_1_TP20R
U3: ESP32_C6_LIBRARY_MAX17048G+T10; ESP32_C6_LIBRARY_SON50P200X200X80-9N

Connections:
3V3/1.7D: C34.2, IC2.C2 (VDD), Q1.2 (S), R5.2, R7.2, R8.2, R_PWR_EPD.2
ALERT/1.6C: U3.5 (!ALERT)
D+/1.5D: D3.4 (I/O2_2)
D-/1.5D: D3.6 (I/O1_2)
DN: D3.1 (I/O1_1), J4.A7 (DN1), J4.B7 (DN2)
DP: D3.3 (I/O2_1), J4.A6 (DP1), J4.B6 (DP2)
EPD_3V3: C1-EP-DR.1, EPD_C5.2, J3.15, J3.16, L5.2, Q1.3 (D)
EPD_BUSY/1.5D: J3.9
EPD_CS/1.4C: J3.12
EPD_DC/1.5D: J3.11
EPD_RST/1.5D: J3.10
GDR: J3.2, Q3.1 (G), R2_EP_DR.2
GND: C1-EP-DR.2, C27.1, C29.1, C30.1, C31.1, C32.1, C34.1, C42.2, C43.2, D3.2 (GND), D4.1 (K), EPD_C1.1, EPD_C2.1, EPD_C5.1, EPD_C6.1, EPD_C7.1, EPD_C8.1, EPD_C9.1, EPD_C10.1, EPD_C11.1, EPD_C12.1, IC2.B1 (IN/TRIG), IC2.B3 (GND), J3.8, J3.17, J3.MP1, J3.MP2, J4.A1_B12 (GND), J4.A12_B1 (GND), J4.SH1 (SHIELD), J4.SH2 (SHIELD), J4.SH3 (SHIELD), J4.SH4 (SHIELD), R1_USB.1, R2_EP_DR.1, R2_USB.2, R_TYPE_SEL.1, SJ1.1, SW_DN.1, SW_ENT.1, SW_UP.1, TP_BAT_GND.TP, U3.1 (CTG), U3.4 (GND), U3.6 (QSTRT), U3.9 (EP); also elsewhere on the board
HAPTIC_EN/1.4C: IC2.A1 (EN)
MOSI/1.5B: J3.14
unnamed: C2-EP-DR.1, D2.1 (K), D4.2 (A)
unnamed: C2-EP-DR.2, D5.2 (A), L5.1, Q3.3 (D)
unnamed: C32.2, IC2.A2 (REG)
unnamed: J4.A5 (CC1), R1_USB.2
unnamed: R1_EP_DR.1, R_TYPE_SEL.2, SJ1.2
unnamed: J4.B5 (CC2), R2_USB.1
unnamed: EPD_C2.2, J3.4
unnamed: EPD_C1.2, J3.5
unnamed: EPD_C6.2, J3.18
unnamed: EPD_C7.2, J3.19
unnamed: EPD_C8.2, J3.20
unnamed: EPD_C10.2, J3.22
OUT+: IC2.A3 (OUT+), TP_OP.TP
OUT-: IC2.C3 (OUT-), TP_ON.TP
P0.13/1.5D: C30.2, R5.1, SW_UP.2
P0.14/1.5D: C31.2, R8.1, SW_ENT.2
P1.01/1.6C: Q1.1 (G), R_PWR_EPD.1
P1.02/1.6C: C29.2, R7.1, SW_DN.2
PREVGH: D5.1 (K), EPD_C11.2, J3.23
PREVGL: D2.2 (A), EPD_C9.2, EPD_C12.2, J3.21
RESE: J3.3, Q3.2 (S), R1_EP_DR.2
SCK/1.5B: J3.13
SCL/1.4C: IC2.C1 (SCL), U3.7 (SCL)
SDA/1.4C: IC2.B2 (SDA), U3.8 (SDA)
VBAT/1.2A: C27.2, TP_VBAT.TP, U3.2 (CELL), U3.3 (VDD)
VBUS/1.5D: C42.1, C43.1, D3.5 (VBUS), J4.A4_B9 (VBUS), J4.A9_B4 (VBUS)

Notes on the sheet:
E-Paper Drive Circuit
Haptic Driver
E-Paper Display Connector
Fuel Gauge
USB C Connector & ESD Protection
Negoita Mihaela

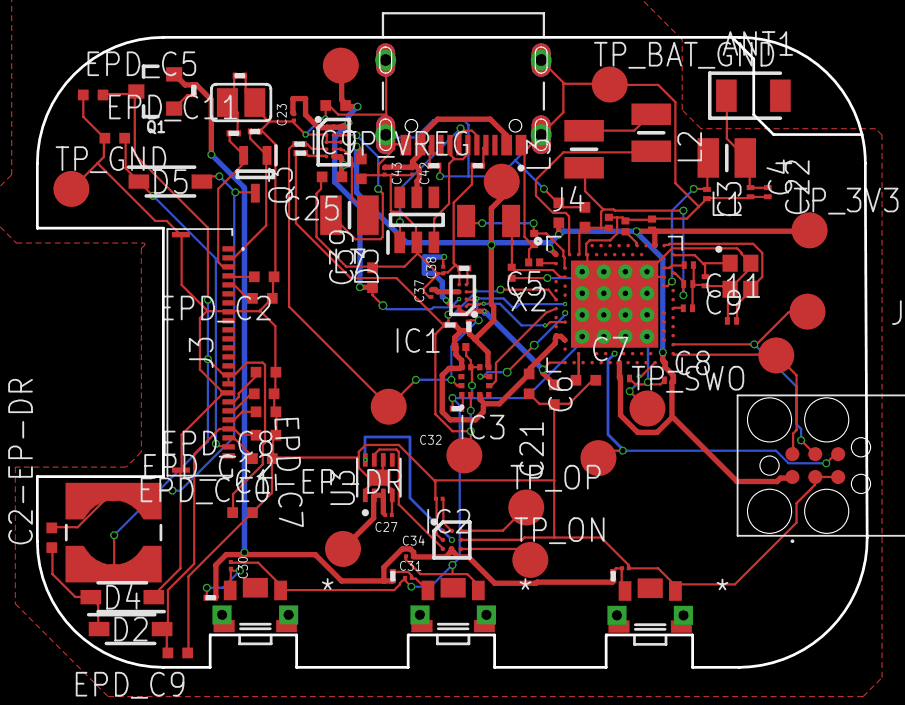
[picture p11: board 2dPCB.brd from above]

Board: 4 copper layers, 46.1 x 35.0 mm, 105 parts (0 on the bottom side), 64 nets.

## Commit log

2026-04-16 pcb 2d updated
    [Tema_TSC.brd]
2026-04-21 Revise README with BOM and hardware specifications

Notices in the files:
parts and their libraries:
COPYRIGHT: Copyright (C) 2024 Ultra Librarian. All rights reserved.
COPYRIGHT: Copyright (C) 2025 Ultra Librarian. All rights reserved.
